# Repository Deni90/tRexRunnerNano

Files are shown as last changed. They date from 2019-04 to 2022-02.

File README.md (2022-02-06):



# Welcome to tRexRunnerNano Project

## About
This project tries to be the smallest implementation of Google's easter egg T-Rex Runner with resolution of only 128x32px.


The goal is to make a small game console by using Atmels Atmega88 microcontroller and SSSD1306 oled display.

## Schematic  & PCB ##
Made with AUTODESK EAGLE 9.0.0

## 3D model ##
Made with FreeCAD 0.18

## DM DIY-MORE OLED-091 ##
Popular I2C OLED 32x128 display from diy-more has an issue. It doesn't properly start after power on, but starts without problems after reset.
To solve this problem swap R3 and R4 resistors.

Solution found at:
https://youtu.be/__3InV5tdzM

## Building ##
```
cd firmware
make hex
```

## Flashing the MCU
Before flashing set up the AVR programmer by changing the value of PROGRAMMER variable in firmware/Makefile.
By default it is set to usbasp.
```
PROGRAMMER = usbasp
```
To flash fuses, firmware and eeprom:
```
cd firmware
make program
```

To flash firmware only:
```
cd firmware
make flash
```

For more information:
```
cd firmware
make
```

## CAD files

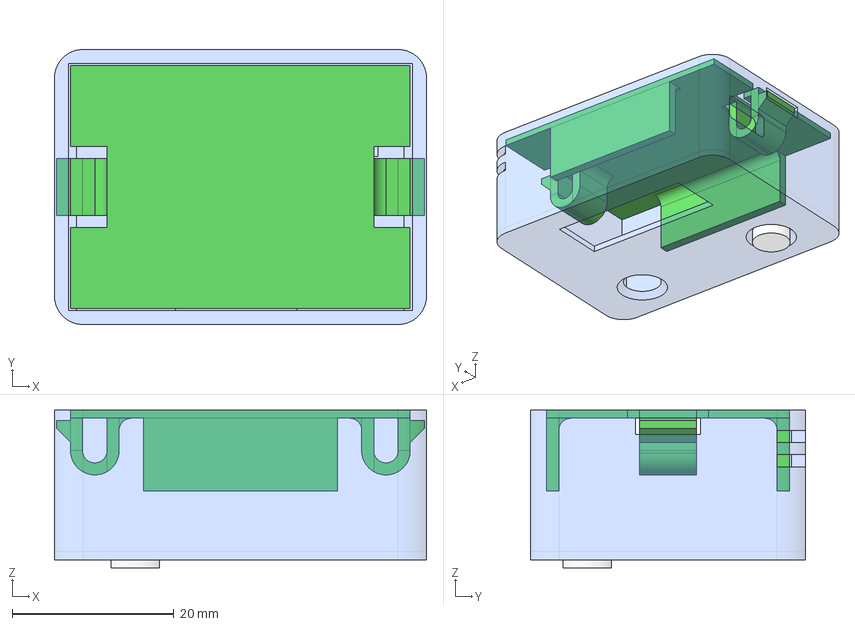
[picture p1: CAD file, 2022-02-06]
casing/tRexRunnerNanoCase.fcstd
46.0 x 34.0 x 19.5 mm
Case
Lid
ButtonCap

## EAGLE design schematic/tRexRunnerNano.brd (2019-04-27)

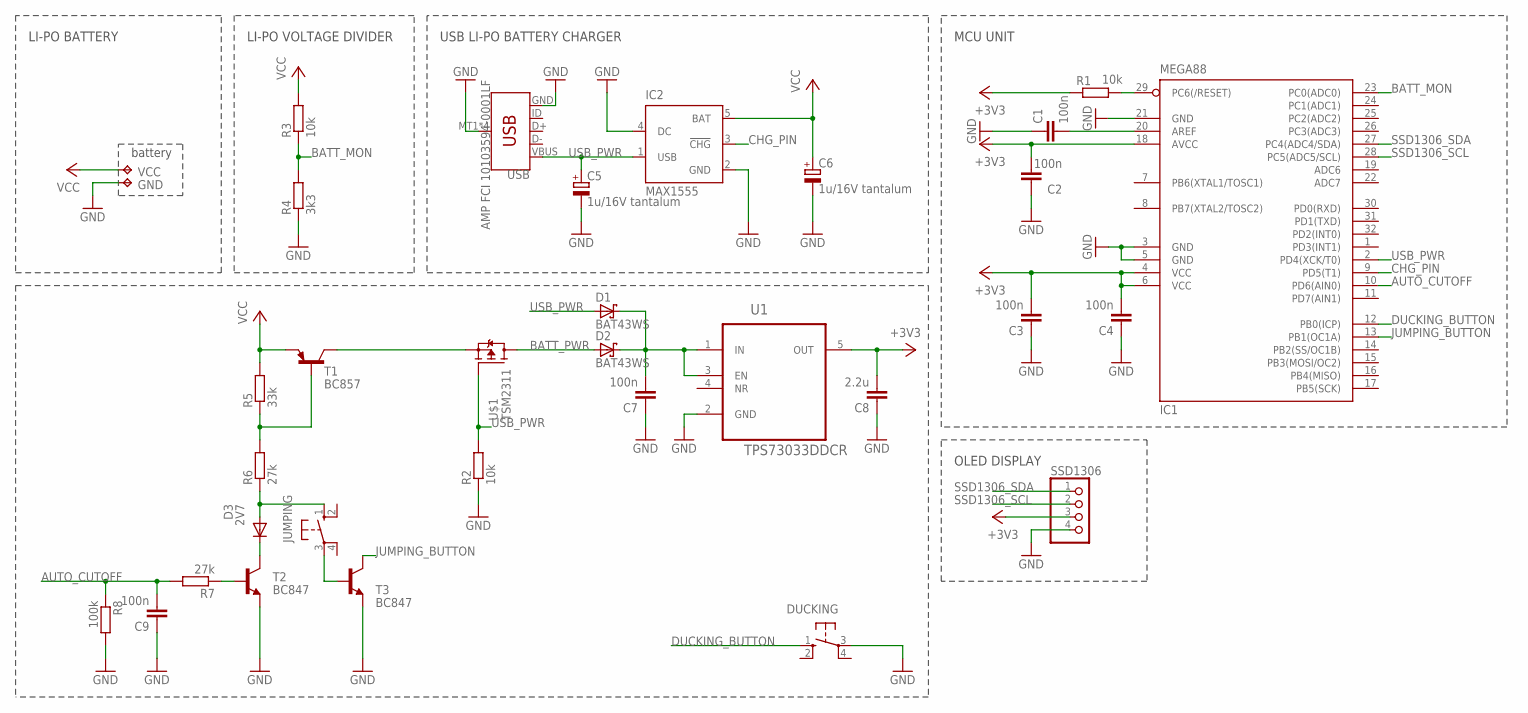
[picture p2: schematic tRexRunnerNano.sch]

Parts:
C1, C2, C3, C4, C7, C9: 100n; C0805
C5, C6: 1u/16V tantalum; SMC_A
C8: 2.2u; C0805
D1, D2: BAT43WS; SOD323_ST
D3: 2V7; SOD80C
DUCKING: 10-XX; B3F-10XX
GND: TPTP12R; TP12R
IC1: MEGA88; TQFP32-08
IC2: MAX1555; SOT23-5L
JUMPING: 10-XX; B3F-10XX
R1, R2, R3: 10k; R0805
R4: 3k3; R0805
R5: 33k; R0805
R6, R7: 27k; R0805
R8: 100k; R0805
SSD1306: PINHD-1X4; 1X04
T1: BC857; SOT23-BEC
T2, T3: BC847; SOT23
U1: TPS73033DDCR; SOT95P290X145-5N
U$1: TSM2311; SOT23
USB: AMP FCI 10103594-0001LF; USB-MICROB
VCC: TPTP12R; TP12R

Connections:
+3V3: C2.2, C3.2, C4.2, C8.2, IC1.4 (VCC), IC1.6 (VCC), IC1.18 (AVCC), R1.1, SSD1306.3, U1.5 (OUT)
AUTO_CUTOFF: C9.2, IC1.10 (PD6(AIN0)), R7.2, R8.1
BATT_MON: IC1.23 (PC0(ADC0)), R3.1, R4.2
BATT_PWR: D2.A, U$1.3 (D)
CHG_PIN: IC1.9 (PD5(T1)), IC2.3 (!CHG)
DUCKING_BUTTON: DUCKING.1 (S), IC1.12 (PB0(ICP))
GND: C1.1, C2.1, C3.1, C4.1, C5.-, C6.-, C7.1, C8.1, C9.1, DUCKING.3, GND.TP, IC1.3 (GND), IC1.5 (GND), IC1.21 (GND), IC2.2 (GND), IC2.4 (DC), R2.1, R4.1, R8.2, SSD1306.4, T2.2 (E), T3.2 (E), U1.2 (GND), USB.GND, USB.MT1 (SHIELD), USB.MT2 (SHIELD), USB.P$1 (SHIELD), USB.P$2 (SHIELD)
JUMPING_BUTTON: IC1.13 (PB1(OC1A)), T3.3 (C)
unnamed: IC1.29 (PC6(/RESET)), R1.2
unnamed: C1.2, IC1.20 (AREF)
unnamed: T1.C, U$1.2 (S)
unnamed: C7.2, D1.C, D2.C, U1.1 (IN), U1.3 (EN)
unnamed: R7.1, T2.1 (B)
unnamed: R5.1, R6.2, T1.B
unnamed: D3.A, JUMPING.1 (S), R6.1
unnamed: D3.C, T2.3 (C)
unnamed: JUMPING.3, T3.1 (B)
SSD1306_SCL: IC1.28 (PC5(ADC5/SCL)), SSD1306.2
SSD1306_SDA: IC1.27 (PC4(ADC4/SDA)), SSD1306.1
USB_PWR: C5.+, D1.A, IC1.2 (PD4(XCK/T0)), IC2.1 (USB), R2.2, U$1.1 (G), USB.VBUS
VCC: C6.+, IC2.5 (BAT), R3.2, R5.2, T1.E, VCC.TP

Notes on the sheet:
MCU UNIT
USB LI-PO BATTERY CHARGER
battery
OLED DISPLAY
LI-PO VOLTAGE DIVIDER
LI-PO BATTERY

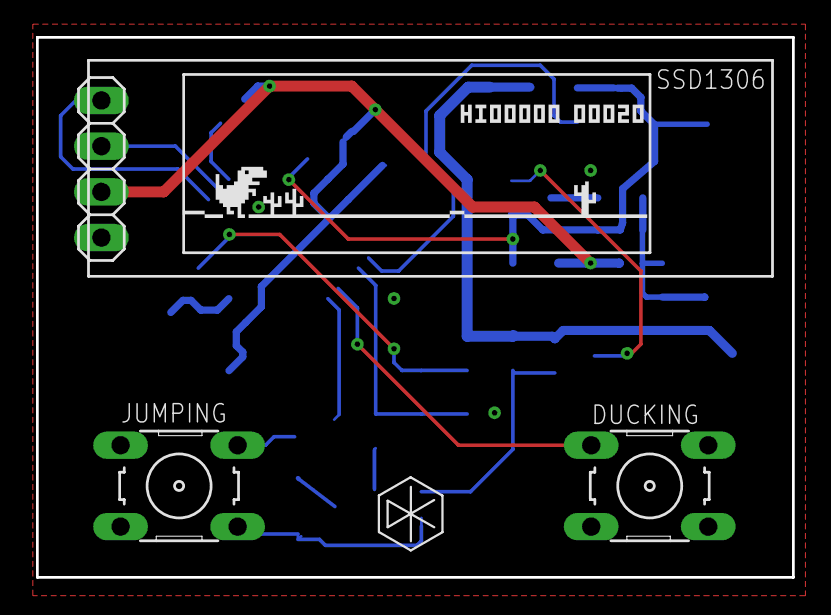
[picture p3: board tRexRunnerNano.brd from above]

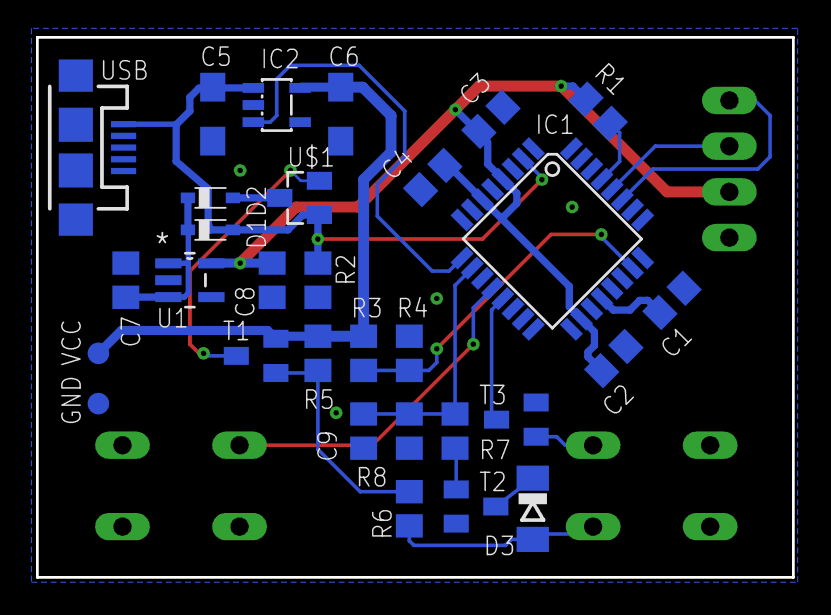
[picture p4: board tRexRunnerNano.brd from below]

Board: 2 copper layers, 42.0 x 30.0 mm, 33 parts (30 on the bottom side), 21 nets.

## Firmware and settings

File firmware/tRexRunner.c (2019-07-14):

/*
 * twi.cpp
 *
 * Created: 21.02.2017 20:17:36
 * Author : Daniel Knezevic
 */

#include <avr/io.h>
#include <avr/interrupt.h>
#include <avr/eeprom.h>
#include <avr/wdt.h>
#include <math.h>
#include <stdlib.h>

#include "tRexRunner.h"

#define CONCAT(a, b)            a ## b
#define CONCAT_EXP(a, b)        CONCAT(a, b)

#define BUTTON_OUTPORT          CONCAT_EXP(PORT, BUTTON_IOPORTNAME)
#define BUTTON_INPORT           CONCAT_EXP(PIN, BUTTON_IOPORTNAME)
#define BUTTON_DDRPORT          CONCAT_EXP(DDR, BUTTON_IOPORTNAME)

#define USB_PWR_OUTPORT          CONCAT_EXP(PORT, USB_PWR_IOPORTNAME)
#define USB_PWR_INPORT           CONCAT_EXP(PIN, USB_PWR_IOPORTNAME)
#define USB_PWR_DDRPORT          CONCAT_EXP(DDR, USB_PWR_IOPORTNAME)

#define CHG_PIN_OUTPORT          CONCAT_EXP(PORT, CHG_PIN_IOPORTNAME)
#define CHG_PIN_INPORT           CONCAT_EXP(PIN, CHG_PIN_IOPORTNAME)
#define CHG_PIN_DDRPORT          CONCAT_EXP(DDR, CHG_PIN_IOPORTNAME)

#define AUTO_CUTOFF_OUTPORT      CONCAT_EXP(PORT, AUTO_CUTOFF_IOPORTNAME)
#define AUTO_CUTOFF_INPORT       CONCAT_EXP(PIN, AUTO_CUTOFF_IOPORTNAME)
#define AUTO_CUTOFF_DDRPORT      CONCAT_EXP(DDR, AUTO_CUTOFF_IOPORTNAME)

#define left_button_state()     (!(BUTTON_INPORT & (1 << LEFT_BUTTON_BIT)))
#define right_button_state()    (!(BUTTON_INPORT & (1 << RIGHT_BUTTON_BIT)))
#define is_usb_connected()      (USB_PWR_INPORT & (1 << USB_PWR_BIT))
#define is_charging_battery()   (!(CHG_PIN_INPORT & (1 << CHG_PIN_BIT)))

static uint8_t frame_buffer[WIDTH * HEIGHT / 8];

volatile uint16_t global_clock = 0;
volatile uint8_t lb_debounce_clock = 0;
volatile uint8_t rb_debounce_clock = 0;
volatile uint16_t game_speed_update_clock = 0;
volatile uint16_t inactivity_clock = 0;
volatile uint16_t battery_monitor_clock = 0;

static float game_speed = GAME_INITIAL_SPEED;
static uint32_t high_score = 0;
static uint32_t score = 0;

static uint8_t button_state = 0x00;
static trex_states_t trex_state = RUNNING;

static horizon_t horizon;
static game_object_t trex;
static game_object_t obstacles[CACTUS_MAX_COUNT + 1]; // last element is pterodactyl

static uint8_t latest_cactus = 0; // index of the newest cactus in the array

static uint16_t obstacle_respawn_base_distance = OBSTACLE_RESPAWN_BASE_DISTANCE;
// make sure WIDTH > OBSTACLE_RESPAWN_BASE_DISTANCE
static uint16_t obstacle_respawn_max_distance = WIDTH - OBSTACLE_RESPAWN_BASE_DISTANCE;
static uint16_t show_pterodactyl = SHOW_PTERODACTYL;

static uint8_t inverted_mode = FALSE;

static uint32_t EEMEM high_score_backup = 0;

static uint16_t battery_voltage = 0;

// lookup table for pterodactyl flying heights
static const __flash uint8_t pterodactyl_flying_heights[] = {
        PTERODACTYL_MIN_FLY_HEIGHT,
        PTERODACTYL_MID_FLY_HEIGHT,
        PTERODACTYL_MAX_FLY_HEIGHT
};
/*
 * Timer1 "Compare Match" ISR
 */
ISR(TIMER1_COMPA_vect, ISR_NOBLOCK)
{
    global_clock++;
    lb_debounce_clock++;
    rb_debounce_clock++;
    game_speed_update_clock++;
    inactivity_clock++;
    battery_monitor_clock++;
}

/*
 * Initialize Timer1
 */
void TIMER_init()
{
    TCCR1B |= (1 << WGM12); // CTC mode of Timer1
    OCR1A = 124;           // OCR1A Timer1's TOP value for 1mS @8Mhz
    TCCR1B |= (1 << CS11) | (1 << CS10); // start Timer1, clkI/O/64 (From prescaler) 125kHz
    TIMSK1 |= (1 << OCIE1A); // Timer/Counter1 Output Compare Match A Interrupt Enable
}

void BUTTONS_init()
{
    BUTTON_OUTPORT |= (1 << LEFT_BUTTON_BIT); // pull up LEFT_BUTTON_IO
    BUTTON_DDRPORT &= ~(1 << LEFT_BUTTON_BIT); // configure LEFT_BUTTON_IO as input

    BUTTON_OUTPORT |= (1 << RIGHT_BUTTON_BIT); // pull up the RIGHT_BUTTON_IO
    BUTTON_DDRPORT &= ~(1 << RIGHT_BUTTON_BIT); // configure RIGHT_BUTTON_IO as input
}

void BUTTONS_monitorButtons()
{
    cli();
    if (lb_debounce_clock >= DEBOUNCE_INTERVAL)
    {
        lb_debounce_clock = 0;
        if (left_button_state())
            button_state |= (1 << LEFT_BUTTON_BIT);
        else
            button_state &= ~(1 << LEFT_BUTTON_BIT);
    } else if ((button_state & (1 << LEFT_BUTTON_BIT)) == left_button_state())
    {
        lb_debounce_clock = 0;
    }

    if (rb_debounce_clock >= DEBOUNCE_INTERVAL)
    {
        rb_debounce_clock = 0;
        if (right_button_state())
            button_state |= (1 << RIGHT_BUTTON_BIT);
        else
            button_state &= ~(1 << RIGHT_BUTTON_BIT);
    } else if ((button_state & (1 << RIGHT_BUTTON_BIT)) == right_button_state())
    {
        rb_debounce_clock = 0;
    }
    sei();
}

void POWER_MANAGER_init()
{
    AUTO_CUTOFF_OUTPORT &= ~(1 << AUTO_CUTOFF_BIT); // pull down AUTO_CUTOFF_BIT
    AUTO_CUTOFF_DDRPORT |= (1 << AUTO_CUTOFF_BIT); // configure AUTO_CUTOFF_BIT as output

    CHG_PIN_OUTPORT |= (1 << CHG_PIN_BIT); // pull up CHG_PIN_BIT
    CHG_PIN_DDRPORT &= ~(1 << CHG_PIN_BIT); // configure CHG_PIN_BIT as input

    USB_PWR_OUTPORT &= ~(1 << USB_PWR_BIT); // pull down USB_PWR_BIT
    USB_PWR_DDRPORT &= ~(1 << USB_PWR_BIT); // configure USB_PWR_BIT as input

    // Initializes ADC on ADC0(PC0) for battery voltage monitoring
    DIDR0 |= (1 << ADC0D);                  // pin 0 disabled
    ADMUX |= (1 << REFS1) | (1 << REFS0); // Internal 1.1V Voltage Reference with external capacitor at AREF pin
    ADCSRA |= (1 << ADPS2) | (1 << ADPS1); // ADC Prescaler Select Bits: 125kHz, prescaler: 64
    ADCSRA |= (1 << ADEN); // ADC Enable
}

#define POWER_MANAGER_turnOn() AUTO_CUTOFF_OUTPORT |= (1 << AUTO_CUTOFF_BIT);

#define POWER_MANAGER_turnOff() AUTO_CUTOFF_OUTPORT &= ~(1 << AUTO_CUTOFF_BIT);

void POWER_MANAGER_MonitorInactivity()
{
    if( button_state )
    {
        inactivity_clock = 0;
    }
    if( inactivity_clock >= INACTIVITY_PERIOD )
    {
        POWER_MANAGER_turnOff();
    }
}

/*
 * Reads battery voltage by using ADC.
 * return value: measured value in mV
 */
uint16_t POWER_MANAGER_ReadBatteryVoltage()
{
    uint16_t read_value = 0;
    ADMUX &= 0xF8;           // clear existing bottom 3 bits. 000 -> ADC0
    ADCSRA |= (1 << ADSC);   // start conversion
    // wait for completion
    while(ADCSRA & (1 << ADSC))
        ;
    read_value = (ADCL | (ADCH << 8));

    // voltage divider R1 = 10k, R2 = 3k3, ADC: 1v1/1024=1.0742mV
    return floor((13300 * 1.0742 * read_value) / 3300);
}

/*
 * Periodically measures battery voltage and if the voltage is under the
 * margin notifies the user with some message and turns off the device
 */
void POWER_MANAGER_MonitorBattery()
{
    if(battery_monitor_clock >= BATTERY_MONITOR_PERIOD)
    {
        battery_monitor_clock = 0;    // reset timer
        battery_voltage = POWER_MANAGER_ReadBatteryVoltage(); // read battery status
        if(battery_voltage <= MIN_BATTERY_VOLTAGE)
        {
            POWER_MANAGER_ShowBatteryStatus((WIDTH - BATTERY_ICON_WITH) / 2, (HEIGHT - BATTERY_ICON_HEIGHT) / 2, 0);
            global_clock = 0;
            while(global_clock < LOW_BATTERY_ALERT_DURATION);
            POWER_MANAGER_turnOff();
            while(1); //wait until the device is powered off
        }
    }
}

void POWER_MANAGER_ShowBatteryStatus(uint8_t x, uint8_t y, uint8_t progress)
{
    FB_Clear();
    FB_DrawRectangle(x + 2, y + 0, 30, 16, FALSE);
    FB_DrawRectangle(x + 0, y + 4, 2, 8, TRUE);

    FB_DrawRectangle(x+ 6, y + 4, progress * 22 / UINT8_MAX, 8, TRUE);
    SSD1306_display(frame_buffer);
}

void FB_Clear()
{
    memset(frame_buffer, 0, sizeof(uint8_t) * (WIDTH * HEIGHT / 8));
}

uint8_t FB_DrawImage(int16_t x, int16_t y, const __flash uint8_t* image, uint8_t width, uint8_t height)
{
    uint8_t collision = FALSE;
    for(int16_t h = y; h < (y + height); h++)
    {
        for(int16_t w = x; w < (x + width); w++)
        {
            if((w >= WIDTH) || (h >= HEIGHT)) continue;
            if( h < 0 || w < 0 ) continue;
            uint16_t buffer_index = WIDTH * (h / 8) + w;
            uint8_t image_w = w - x;
            uint8_t image_h = h - y;
            uint16_t image_index = width * (image_h / 8) + image_w;
            if((image[image_index] >> (image_h % 8) & 0x01) == 0x01)
            {
                if(frame_buffer[buffer_index] >> (h % 8) & 0x01)
                    collision = TRUE;
                frame_buffer[buffer_index]|=(1 << (h % 8));
            }
        }
    }
    return collision;
}

void FB_DrawUnsignedValue(int16_t x, int16_t y, uint32_t value)
{
    int16_t xx = x;
    for (uint32_t dividend = 10000; dividend > 0; dividend /= 10)
    {
        FB_DrawImage(xx, y, &digits[(value / dividend % 10) * DIGIT_WIDTH],
                DIGIT_WIDTH, DIGIT_HEIGHT);
        xx += DIGIT_WIDTH;
    }
}

uint8_t FB_DrawGameObject(game_object_t game_object)
{
    if(!game_object.visible)
        return FALSE;
    return FB_DrawImage(floor(game_object.x), floor(game_object.y),
            game_object.sprite, game_object.width, game_object.height);
}

void FB_SetPixel(uint8_t x, uint8_t y)
{
    if((x >= WIDTH) || (y >= HEIGHT)) return;
    uint16_t buffer_index = WIDTH * (y / 8) + x;
    frame_buffer[buffer_index] |= (1 << (y % 8));
}

void FB_InvertColor()
{
    for(uint16_t i = 0; i < (WIDTH * HEIGHT / 8); i++)
    {
        frame_buffer[i] = ~frame_buffer[i];
    }
}

void FB_DrawRectangle(uint8_t x, uint8_t y, uint8_t width, uint8_t height, uint8_t fill)
{
    if((x >= WIDTH) || (y >= HEIGHT)) return;

    uint8_t a, b;

    if((y + height) > HEIGHT)
    {
        a = HEIGHT;
    }
    else
    {
        a = y + height;
    }

    if((x + width) > WIDTH)
     {
         b = WIDTH;
     }
     else
     {
         b = x + width;
     }

    for(uint8_t i = y; i < a; i++)
    {
        for(uint8_t j = x; j < b; j++)
        {
            if(fill)
            {
                FB_SetPixel(j, i);
            } else
            {
                if(i == y || i == (a - 1) || j == x || j == (b - 1))
                {
                    FB_SetPixel(j, i);
                }
            }
        }
    }
}

void GAME_InitHorizon()
{
    horizon.x = 0;
    horizon.y = HEIGHT - HORIZON_LINE_HEIGHT;
    horizon.width = HORIZON_LINE_WIDTH;
    horizon.height = HORIZON_LINE_HEIGHT;
    horizon.bump1_x = HORIZON_LINE_BUMP1_X;
    horizon.bump1_width = HORIZON_LINE_BUMP1_WIDTH;
    horizon.bump2_x = HORIZON_LINE_BUMP2_X;
    horizon.bump2_width = HORIZON_LINE_BUMP2_WIDTH;
}

void GAME_UpdateHorizon()
{
    for(uint8_t i = horizon.x; i < horizon.width; i++)
    {
        // create some space between trex and horizon
        if(trex_state == RUNNING &&
                (i >= trex.x + TREX_STANDING_CLEARENCE_MIN) &&
                (i < trex.x + TREX_STANDING_CLEARENCE_MAX))
            continue;
        if(trex_state == RUNNING &&
                (i >= trex.x + TREX_STANDING_CLEARENCE_MIN) &&
                (i < trex.x + TREX_STANDING_CLEARENCE_MAX))
            continue;
        if(trex_state == JUMPING &&
                (i >= trex.x + TREX_STANDING_CLEARENCE_MIN) &&
                (i < trex.x + TREX_STANDING_CLEARENCE_MAX) &&
                (trex.y > trex.height + 1))
            continue;
        if(trex_state == DUCKING &&
                (i >= trex.x + TREX_DUCKING_CLEARENCE_MIN) &&
                (i < trex.x + TREX_DUCKING_CLEARENCE_MAX))
            continue;

        int8_t bump1_xx = floor(horizon.bump1_x);
        int8_t bump2_xx = floor(horizon.bump2_x);

        if(i >= bump1_xx && i < bump1_xx + horizon.bump1_width)
            // draw first bump
            FB_SetPixel(i, horizon.y);
        else if(i >= bump2_xx && i < bump2_xx + horizon.bump2_width)
             // draw second bump
            FB_SetPixel(i, horizon.y);
        else
            // draw horizon line
            FB_SetPixel(i, horizon.y + 1);
    }

    // move bumps
    if (horizon.bump1_x - game_speed > 0)
    {
        horizon.bump1_x -= game_speed;
    }
    else
    {
        horizon.bump1_x = horizon.width;
    }

    if (horizon.bump2_x - game_speed > 0)
    {
        horizon.bump2_x -= game_speed;
    }
    else
    {
        horizon.bump2_x = horizon.width;
    }
}

void GAME_InitPrerodactyl(game_object_t *pterodactyl)
{
    pterodactyl->sprite = pterodactyl1;
    pterodactyl->x = 0 - PTERODACTYL_WIDTH;
    pterodactyl->y = 0 - PTERODACTYL_HEIGHT;
    pterodactyl->width = PTERODACTYL_WIDTH;
    pterodactyl->height = PTERODACTYL_HEIGHT;
    pterodactyl->visible = TRUE;
}

void GAME_CreatePterodactyl(game_object_t *pterodactyl)
{
    pterodactyl->x = WIDTH;
    uint8_t temp = rand() % PTERODACTYL_FLYING_HEIGHTS_CNT;
    pterodactyl->y = pterodactyl_flying_heights[temp];
    pterodactyl->width = PTERODACTYL_WIDTH;
    pterodactyl->height = PTERODACTYL_HEIGHT;
    pterodactyl->sprite = pterodactyl1;
    pterodactyl->visible = TRUE;
}

void GAME_UpdatePterodactyl(game_object_t *pterodactyl)
{
    static unsigned int flapping_counter = 0;

    if(!pterodactyl->visible)
        return;

    if (++flapping_counter >= PTERODACTYL_WING_SWAP)
    {
        flapping_counter = 0;

        if (pterodactyl->sprite == pterodactyl1)
        {
            pterodactyl->sprite = pterodactyl2;
        } else
        {
            pterodactyl->sprite = pterodactyl1;
        }
    }
    FB_DrawGameObject(*pterodactyl);

    // move to the left in small steps
    if (pterodactyl->x + pterodactyl->width > 0)
    {
        pterodactyl->x -= game_speed;
    } else
    {
        pterodactyl->visible = FALSE;
    }
}
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
int main()
{
    POWER_MANAGER_init();
    POWER_MANAGER_turnOn();
    TIMER_init();
    sei();
    wdt_enable(WDTO_1S); // enable 1s watchdog timer
    SSD1306_init();
    SSD1306_clear();

    uint8_t button_released = FALSE;    // used to prevent immediate restart of the game while holding the jumping button

    uint8_t bar = 0;
    uint8_t battery_x = (WIDTH - BATTERY_ICON_WITH) / 2;
    uint8_t battery_y = (HEIGHT - BATTERY_ICON_HEIGHT) / 2;
    // wait until the USB is connected
    while(is_usb_connected())
    {
        if(is_charging_battery())
        {
            // charging in progress
            if(global_clock >= 10)
            {
                global_clock = 0;
                POWER_MANAGER_ShowBatteryStatus(battery_x, battery_y, ++bar);
                if(bar == 0)
                {
                    battery_x += 10;
                    if(battery_x >= (WIDTH - BATTERY_ICON_WITH))
                    {
                        battery_x = 0;
                    }
                }
            }
        }
        else
        {
            // battery is full
            if(global_clock >= 2550)
            {
                global_clock = 0;
                POWER_MANAGER_ShowBatteryStatus(battery_x, battery_y, UINT8_MAX);
                battery_x += 10;
                if(battery_x >= (WIDTH - BATTERY_ICON_WITH))
                {
                    battery_x = 0;
                }
            }
        }
        wdt_reset(); // keep the watchdog happy
    }

    // before startup check the battery status: if low -> turn off the device
    battery_voltage = POWER_MANAGER_ReadBatteryVoltage();
    if( battery_voltage < MIN_BATTERY_VOLTAGE)
    {
        POWER_MANAGER_ShowBatteryStatus((WIDTH - BATTERY_ICON_WITH) / 2, (HEIGHT - BATTERY_ICON_HEIGHT) / 2, 0);
        global_clock = 0;
        while(global_clock < LOW_BATTERY_ALERT_DURATION)
        {
            wdt_reset(); // keep the watchdog happy
        }
        POWER_MANAGER_turnOff();
        while(1); //wait until the device is powered off
    }

    // startup, turning on the device
    FB_Clear();
    FB_DrawRectangle(PROGRESS_BAR_X, PROGRESS_BAR_Y, PROGRESS_BAR_WIDTH, PROGRESS_BAR_HEIGHT, FALSE);
    SSD1306_display(frame_buffer);
    BUTTONS_init();

    global_clock = 0; // reset timer
    while(1)
    {
        if(global_clock >= TIMEOUT_INTERVAL)
        {
            POWER_MANAGER_turnOff();
            while(1); //wait until the device is powered off
        }
        BUTTONS_monitorButtons();
        if(button_state == ((1 << LEFT_BUTTON_BIT) | (1 << RIGHT_BUTTON_BIT)))
        {
            global_clock = 0; // reset timer
            while(global_clock < STARTUP_INTERVAL)
            {
                wdt_reset(); // keep the watchdog happy
                // Update progress bar
                FB_Clear();
                FB_DrawRectangle(PROGRESS_BAR_X, PROGRESS_BAR_Y, PROGRESS_BAR_WIDTH, PROGRESS_BAR_HEIGHT, FALSE);
                uint16_t step = STARTUP_INTERVAL / 90;
                FB_DrawRectangle(PROGRESS_BAR_X, PROGRESS_BAR_Y, global_clock / step , PROGRESS_BAR_HEIGHT, TRUE);
                SSD1306_display(frame_buffer);
                BUTTONS_monitorButtons();
                // check if the buttons are released in the meantime, if yes turn off the device
                if(button_state != ((1 << LEFT_BUTTON_BIT) | (1 << RIGHT_BUTTON_BIT)))
                {
                    POWER_MANAGER_turnOff();
                    while(1); //wait until the device is powered off
                }
            }
            break;
        }
    }

    // initialize the game
    GAME_Init();

    // wait until the buttons are released to prevent automatic start of the game
    global_clock = 0;
    while(button_state)
    {
        if((button_state & (1 << LEFT_BUTTON_BIT)) &&
                (button_state & (1 << RIGHT_BUTTON_BIT)))
        {
            if(global_clock >= HIGH_SCORE_RESET_TIME && high_score != 0)
            {
                cli();
                high_score = 0;
                eeprom_write_block(&high_score, &high_score_backup, sizeof(high_score_backup));
                sei();
                GAME_Init();
            }
        }
        wdt_reset(); // keep the watchdog happy
        BUTTONS_monitorButtons();
        POWER_MANAGER_MonitorBattery();
    }

    // wait for button press to start the game
    while(1)
    {
        if(!(button_state & ( 1 << LEFT_BUTTON_BIT)))
        {
            button_released = TRUE;
        }
        if(button_state && button_released)
        {
            button_released = FALSE;
            break;
        }
        wdt_reset(); // keep the watchdog happy
        BUTTONS_monitorButtons();
        POWER_MANAGER_MonitorInactivity();
        POWER_MANAGER_MonitorBattery();
    }

    srand(global_clock);    // initialize PRNG

    while(1)
    {
        BUTTONS_monitorButtons();
        POWER_MANAGER_MonitorInactivity();
        POWER_MANAGER_MonitorBattery();
        wdt_reset(); // keep the watchdog happy
        /* GAME OVER */
        if(trex_state == CRASHED)
        {
            if(!(button_state & (1 << LEFT_BUTTON_BIT)))
                button_released = TRUE;

            // wait for jump button to restart the game
            if((button_state & (1 << LEFT_BUTTON_BIT)) && button_released)
            {
                button_released = FALSE;
                GAME_Init();
            } else
            {
                if(inverted_mode) FB_InvertColor(); // restore to original buffer
                FB_DrawImage(WIDTH /2 - GAME_OVER_SPLASH_WIDTH / 2,
                        10, game_over_splash, GAME_OVER_SPLASH_WIDTH,
                        GAME_OVER_SPLASH_HEIGHT);
                if(inverted_mode) FB_InvertColor(); // invert back
                if(score > high_score)
                {
                    SSD1306_clear();
                    high_score = score;
                    cli();
                    eeprom_write_block(&high_score, &high_score_backup, sizeof(high_score_backup));
                    sei();
                }
                SSD1306_display(frame_buffer);
                continue;
            }
        }

        GAME_HandleState();

        if (global_clock >= RENDER_PERIOD)
        {
            global_clock = 0;

            FB_Clear();

            GAME_ShowScore();

            GAME_UpdateHorizon();

            // create new obstacles
            if(GAME_CountVisibleCactuses(obstacles) < CACTUS_MAX_COUNT)
            {
                uint8_t previous_cactus;
                if(latest_cactus > 0)
                {
                    previous_cactus = latest_cactus - 1;
                } else
                {
                    previous_cactus = CACTUS_MAX_COUNT - 1;
                }
                if(obstacles[latest_cactus].visible == FALSE &&
                        !obstacles[PTERODACTYL].visible)
                {
                    if((int)obstacles[previous_cactus].x <= (WIDTH - 
                            obstacles[previous_cactus].width) ||
                            !obstacles[previous_cactus].visible)
                    {
                        GAME_CreateCactus(&obstacles[latest_cactus]);
                        uint16_t random_distance =
                                obstacle_respawn_base_distance +
                                rand() % obstacle_respawn_max_distance;
                        obstacles[latest_cactus].x += random_distance;
                        // respawn pterodatyl?
                        if(random_distance >= show_pterodactyl)
                        {
                            // replace cactus with pterodactyl
                            obstacles[latest_cactus].visible = FALSE;
                            GAME_CreatePterodactyl(&obstacles[CACTUS_MAX_COUNT]);
                            obstacles[PTERODACTYL].x += random_distance;
                        }
                        latest_cactus++;
                    }
                }
                if(latest_cactus == CACTUS_MAX_COUNT)
                {
                    latest_cactus = 0;
                }
            }

            // update cactuses
            for(uint8_t i = 0; i < CACTUS_MAX_COUNT; i++)
            {
                GAME_UpdateCactus(&obstacles[i]);
            }
            // update pterodactyl
            GAME_UpdatePterodactyl(&obstacles[PTERODACTYL]);

            // update trex
            GAME_UpdateTrex();
            if(inverted_mode) FB_InvertColor();
            /* RENDER */
            SSD1306_display(frame_buffer);
        }
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

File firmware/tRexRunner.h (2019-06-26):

/*
 * tRexRunner.h
 *
 *  Created on: Jul 15, 2018
 *      Author: Daniel Knezevic
 */

#ifndef TREXRUNNER_H_
#define TREXRUNNER_H_

#include "ssd1306/ssd1306.h"
#include "sprites.h"

#define WIDTH                           SSD1306_LCDWIDTH
#define HEIGHT                          SSD1306_LCDHEIGHT

#define RENDER_PERIOD                   20 // 50 FPS

#define TREX_RUNNING_SPEED              2
#define TREX_MAX_JUMP_HEIGHT            (HEIGHT - HORIZON_LINE_HEIGHT - 2)

#define CACTUS_MAX_COUNT                3

#define PTERODACTYL                     CACTUS_MAX_COUNT
#define PTERODACTYL_WING_SWAP           8
#define PTERODACTYL_FLYING_HEIGHTS_CNT  3
#define PTERODACTYL_MIN_FLY_HEIGHT      (HEIGHT - PTERODACTYL_HEIGHT)
#define PTERODACTYL_MID_FLY_HEIGHT      (HEIGHT - TREX_DUCKING_HEIGHT - 3 - PTERODACTYL_HEIGHT)
#define PTERODACTYL_MAX_FLY_HEIGHT      (HEIGHT - TREX_STANDING_HEIGHT - 3 - PTERODACTYL_HEIGHT)

#define OBSTACLE_RESPAWN_BASE_DISTANCE  50  // px
#define OBSTACLE_RESPAWN_DISTANCE_INC   5   // px
#define SHOW_PTERODACTYL                120 // px

#define GAME_GRAVITY                    3.2f
#define GAME_INITIAL_SPEED              3.9f
#define GAME_SPEED_DELTA                0.4f
#define JUMPING_SPEED                   3.5f
#define GAME_SCORE_INCREMENT            70 // mS

#define INVERTED_MODE_THRESHOLD         1000

#define HI_SCORE_Y                      1

#define DEBOUNCE_INTERVAL               50

#define BUTTON_IOPORTNAME               B
#define LEFT_BUTTON_BIT                 1
#define RIGHT_BUTTON_BIT                0

#define USB_PWR_IOPORTNAME              D
#define USB_PWR_BIT                     4

#define CHG_PIN_IOPORTNAME              D
#define CHG_PIN_BIT                     5

#define AUTO_CUTOFF_IOPORTNAME          D
#define AUTO_CUTOFF_BIT                 6

#define TRUE                            1
#define FALSE                           0

#define TIMEOUT_INTERVAL                1500 // mS
#define STARTUP_INTERVAL                1000 // mS

#define INACTIVITY_PERIOD               30000 // mS

#define MIN_BATTERY_VOLTAGE             3600 // mV
#define BATTERY_MONITOR_PERIOD          30000 // milliseconds

#define LOW_BATTERY_ALERT_DURATION      1500 // mS

#define HIGH_SCORE_RESET_TIME           10000 //mS

typedef enum trex_states_e {
    RUNNING = 0, DUCKING, JUMPING, CRASHED
} trex_states_t;

typedef struct game_object_s {
    float x;
    float y;
    uint8_t width;
    uint8_t height;
    const uint8_t *sprite;
    uint8_t visible;
} game_object_t;

typedef struct horizon_s {
    int16_t x;
    int16_t y;
    uint8_t width;
    uint8_t height;
    float bump1_x;
    uint8_t bump1_width;
    float bump2_x;
    uint8_t bump2_width;
} horizon_t;

void TIMER_init();

void BUTTONS_init();
void BUTTONS_monitorButtons();

void POWER_MANAGER_init();
void POWER_MANAGER_MonitorInactivity();
uint16_t POWER_MANAGER_ReadBatteryVoltage();
void POWER_MANAGER_MonitorBattery();
void POWER_MANAGER_ShowBatteryStatus(uint8_t x, uint8_t y, uint8_t progress);

void FB_Clear();
uint8_t FB_DrawImage(int16_t x, int16_t y, const __flash uint8_t* image, uint8_t width, uint8_t height);
void FB_DrawUnsignedValue(int16_t x, int16_t y, uint32_t value);
uint8_t FB_DrawGameObject(game_object_t game_object);
void FB_SetPixel(uint8_t x, uint8_t y);
void FB_InvertColor();
void FB_DrawRectangle(uint8_t x, uint8_t y, uint8_t width, uint8_t height, uint8_t fill);

void GAME_Init();
void GAME_ShowScore();
void GAME_HandleState();
void GAME_AdjustDifficulty();

void GAME_InitHorizon();
void GAME_UpdateHorizon();

void GAME_InitPrerodactyl(game_object_t *pterodactyl);
void GAME_CreatePterodactyl(game_object_t *pterodactyl);
void GAME_UpdatePterodactyl(game_object_t *pterodactyl);

void GAME_InitCactus(game_object_t *cactus);
void GAME_CreateCactus(game_object_t *cactus);
void GAME_UpdateCactus(game_object_t *cactus);
uint8_t GAME_CountVisibleCactuses(game_object_t cactus[]);

void GAME_InitTrex();
void GAME_UpdateRunningTrex();
void GAME_UpdateDuckingTrex();
void GAME_UpdateJumpingTrex();
void GAME_UpdateTrex();

#endif /* TREXRUNNER_H_ */

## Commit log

2018-07-16 Initializes timer.
2018-07-17 Adds button handling and miror changes
    - handles buttons
    - updates trex state based on buttons activity
    - changes game parameters
    - adds FB_drawGameObject function
2018-07-17 Fixes formatting game_object definitions
    [tRexRunner.c]
2018-07-18 Refactors button handling
    - button io initialization moved to function
    - created button state monitor
2018-07-23 Renamed FB_functions, replaces button pins with macros
    [tRexRunner.c, tRexRunner.h]
2018-07-23 Adds clearance between new horizon and trex.
    [tRexRunner.c, tRexRunner.h]
2018-07-30 Replaces cactus3 with different design.
    [tRexRunner.c]
2018-07-30 Fixes trex ducking glitch.
    [tRexRunner.c]
2018-07-31 Fixes dead trex sprite and minor changes.
    [tRexRunner.c]
2018-08-02 Refactoring
    - merges cactuses and pterodactyl into obstacles
    - changes game_objects update functions
    - fixes initialization of cactuses
    [tRexRunner.c, tRexRunner.h]
2018-08-02 Tunes game parameters, updates Makefile
    - frame rate dropped to 50FPS
    - MCU frequency set to 8MHz
    - updated MCU fuse bits
2018-08-02 Fixes trex crash into horizon during landing.
    [tRexRunner.c]
2018-08-06 Removes debug print.
2018-08-09 Introduces inverted color mode.
    [tRexRunner.c, tRexRunner.h]
2018-08-09 Fixes trexs jumping height, moves score 1px down.
    [tRexRunner.c, tRexRunner.h]
2018-09-04 Adds initial hardware desing.
    [tRexRunnerNano.brd, tRexRunnerNano.sch]
2018-09-05 Changes via sizes.
    [tRexRunnerNano.brd]
2018-10-10 Adds power manager and initializes io pins.
2018-10-10 Code refactoring by moving it info functions.
    - GAME_AdjustDifficulty: increasing game speed and distance between obstacles
    - GAME_HandleState: switching trex states based on button presses
2018-11-19 Fixes read/write from/to eeprom.
    [tRexRunner.c, tRexRunner.h]
2018-11-19 Implements battery monitoring.
2018-11-21 Implements the startup of the device.
    To start the device both buttons should be held for STARTUP_INTERVAL.
    - new function FB_DrawRectangle
    - deleted unused TIMER_delay
2018-11-21 Removes unused functions and refactores code.
    - removed FB_ClearPixel
    - POWER_MANAGER_turnOn and POWER_MANAGER_turnOff converted to macros
    - removed GAME_BackupHighScore and GAME_RestoreHighScore
2018-11-21 Fixes trex jumping height.
    [sprites.h, tRexRunner.c, tRexRunner.h]
2019-01-08 Fixes typo and POWER_MANAGER_ReadBatteryVoltage
    [tRexRunner.c]
2019-01-08 Implement power management (usb & battery charging)
    - created POWER_MANAGER_ShowBatteryStatus for showing battery icon
    - added checking for low battery
    - fixed intialization of CHG_PIN
    - declared TIMER, BUTTON and POWER_MANAGER functions in the header
    [sprites.h, tRexRunner.c, tRexRunner.h]
2019-01-08 Small adjustments of OLED and USB connectors
    - OLED connector has been moved 1mm left
    - micro USB connector has been moved 1mm right
    [tRexRunnerNano.brd]
2019-01-08 Schematic: Changes D3 to 2V7
    [tRexRunnerNano.brd, tRexRunnerNano.sch]
2019-01-16 Fixes the horizon when trex is jumping.
    [tRexRunner.c]
2019-01-17 Board: Repositions oled connector, usb and buttons
    [tRexRunnerNano.brd]
2019-03-12 Fixes turning off when the init isn't successful
    [tRexRunner.c]
2019-03-12 Fixes Timer1's TOP value for 1mS
    [tRexRunner.c]
2019-04-27 Adds watchdog timer.
2019-04-27 Fixes early start of the game at startup.
    [tRexRunner.c]
2019-04-27 Repositions ssd1306 text on PCB
    [tRexRunnerNano.brd]
2019-04-29 Reimplements: Fix for early start of the game at startup.
    - no need for using timer
    [tRexRunner.c]
2019-05-05 Prevents immediate start of the game after gameover
    [tRexRunner.c]
2019-06-25 Implements reseting high score.
    [tRexRunner.c, tRexRunner.h]
2019-06-26 Fizes oled burn while charging battery.
    [tRexRunner.c, tRexRunner.h]
2019-06-26 Fixes bugs when turning off the device.
    [tRexRunner.c]
2019-09-16 Enables EESAVE fuse bit to preserve eeprom.
2022-02-06 Adds 3D model for casing
    [tRexRunnerNanoCase.fcstd]

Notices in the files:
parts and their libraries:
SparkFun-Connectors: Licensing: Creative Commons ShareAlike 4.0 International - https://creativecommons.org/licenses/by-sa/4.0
